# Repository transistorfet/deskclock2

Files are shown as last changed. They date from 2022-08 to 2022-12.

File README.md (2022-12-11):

DeskClock 2
===========

###### *Started July 31, 2022*

A desktop companion device for displaying status and controlling things without interrupting flow.
This is a replacement to my previous deskclock project which was originally built in 2009 and later
revamped with an Arduino in 2012.

The new design has an LCD screen, 8 CherryMX buttons, a temperature sensor, an IR receiver, and a
USB connection to my desktop computer.  The controller is a
[Adafruit Feather STM32F405 Express](https://learn.adafruit.com/adafruit-stm32f405-feather-express)
programmed using the Arudino framework.  The computer is running
[Nerve](http://jabberwocky.ca/projects/nerve/), which can perform actions in response to the
buttons, and display information like the current time, current song playing on my computer, and
indoor and outdoor temperature (where the outdoor temperature is broadcast from another computer,
which receives it from a wireless sensor outside).  The buttons are currently configured to control
the music player on my computer, as well as toggle some lights in my computer room.

Custom PCB
----------

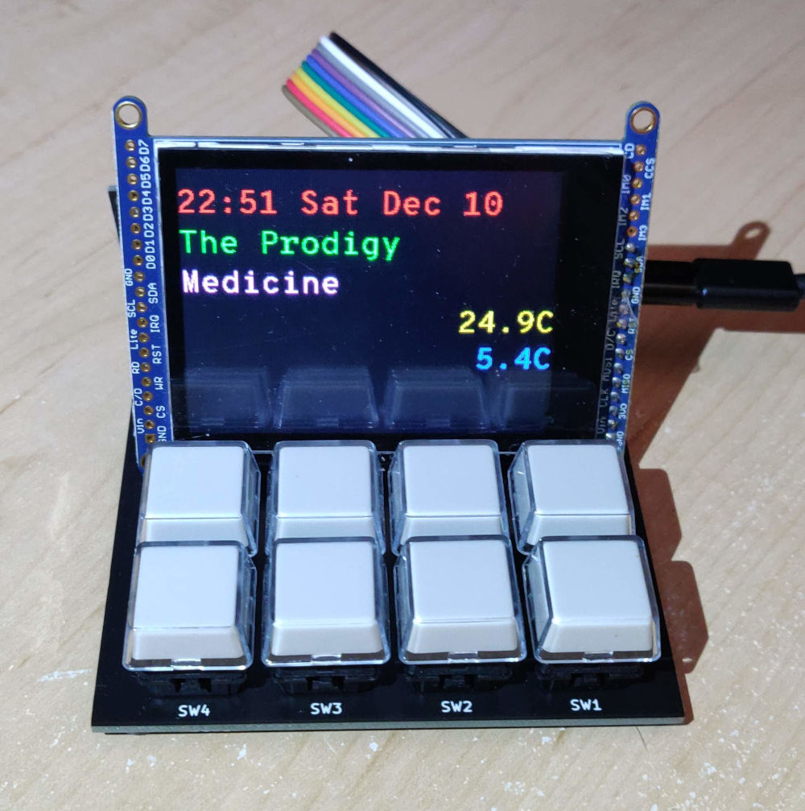
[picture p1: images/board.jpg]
The board in its place under one of my side monitors


Above is the assembled board.  It was designed in November 2022, and assembled in December.

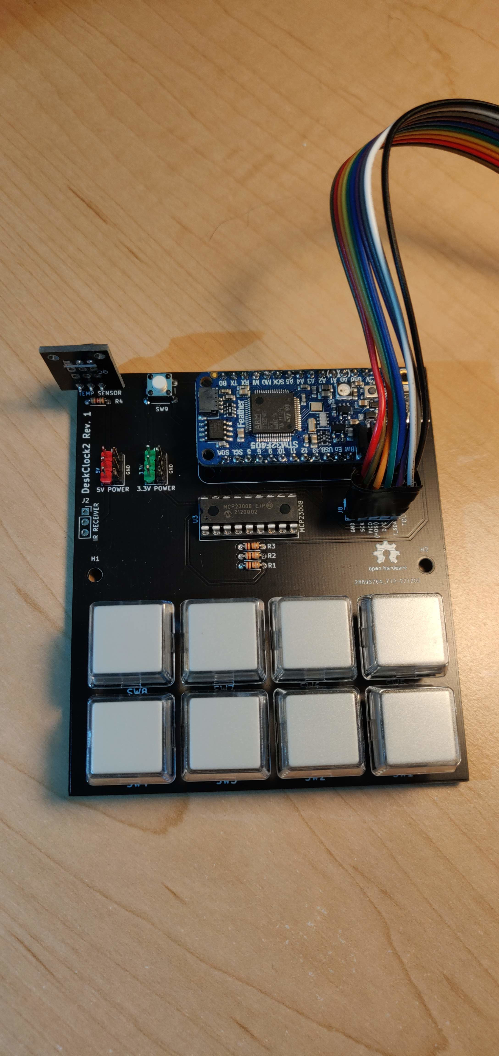
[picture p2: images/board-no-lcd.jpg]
Top view of the assembled board without the LCD showing the components


Top down view of the board without the LCD resting on top.  It's a pretty simple design with
an MCP23008 I2C GPIO chip for reading the buttons.

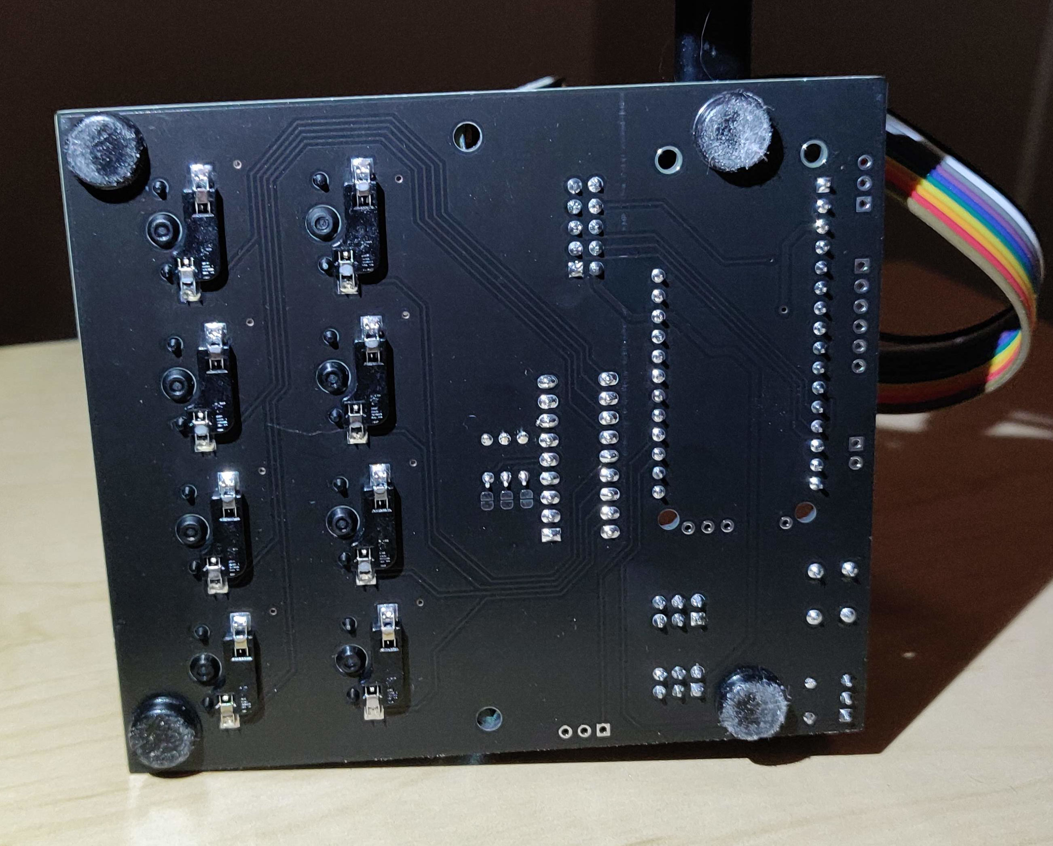
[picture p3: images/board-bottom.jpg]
Bottom view of the assembled board showing the Kali solderless keyboard button sockets


On the bottom, you can see the Kali solderless keyboard button sockets, which are compatible with
CherryMX switches.  They were surprisingly easy to install, align, and solder, using a pre-made
KiCAD footprint.  The sockets snap snugly into the board with no room to wiggle.  I also stuck
some rubber feet to the bottom to clear the sockets from touching the desk, and also to keep it in
place when pressing buttons.

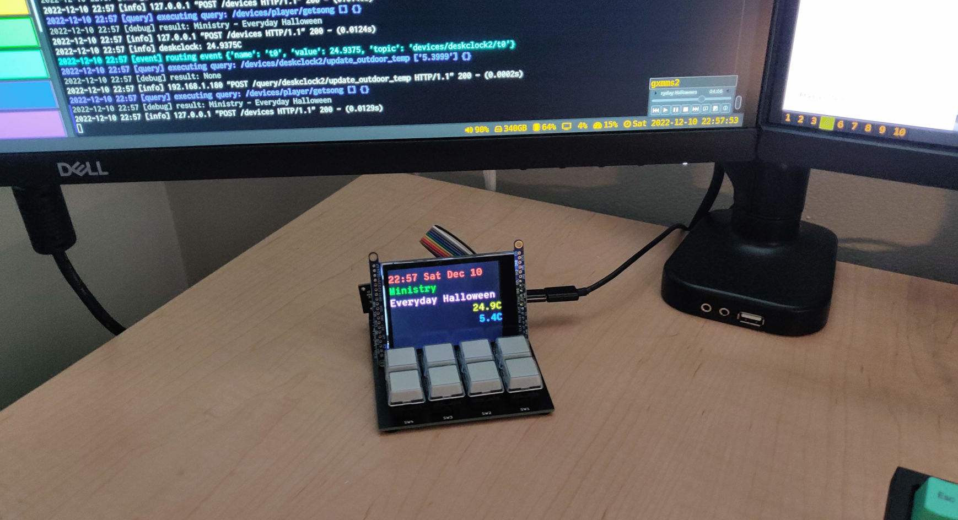
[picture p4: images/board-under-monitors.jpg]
The assembled board, wider view including the monitor with the Python program's log messages showing some communication with the device


The assembled board with the LCD floating (not securely attached). On the monitor above, you can
see the Python program's log messages showing it receiving the outdoor temperature and sending it
to DeskClock2, and querying the current song to be displayed.

A mistake was made on the board for the IR receiver, which has the power pins reversed.  I attached
a 3 pin header to the board, and with some shrink wrap on one of the pins, bent the power pins to
be reversed when plugged in.

Prototype
---------

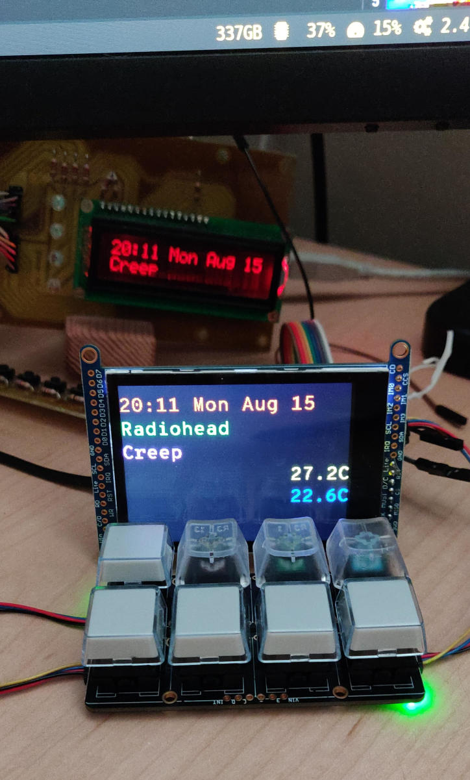
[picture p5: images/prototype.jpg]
Prototype using AdaFruit NeoKeys and 2.8 inch LCD


Above is the prototype, with the old deskclock to be replaced visible in the background

The prototype is built using an Adafruit
[Feather STM32F405 Express](https://learn.adafruit.com/adafruit-stm32f405-feather-express) with two
[NeoKeys](https://www.adafruit.com/product/4980) and a
[2.8 inch LCD](https://www.adafruit.com/product/2090).

Programming with Arduino
------------------------

In the Arduino IDE:

- select board "Generic STM32F4 Series"
- select board part number "Adafruit Feather STM32F405"
- select USB support "CDC (generic 'Serial' supersede USART)
- select upload method "STM32CubeProgrammer (DFU)"

To put the device in programming mode, hold down the reset button on the Feather, and the Flash button
on the board, and then release the reset button first.

Communication
-------------

The Feather appears as a generic serial-over-USB device.  The protocol is a very simple text format
where each line has a sub-device name/number, followed by an equals sign, and then the data.  For a
button, the device would send "B5=1" when the button is pressed, and "B5=0" when released, where the
number in the name corresponds to the button number between 0 and 7.  The temperature is sent back
as "T0=23.0" where the value is in Celsius.

For the LCD, each of 5 lines is drawn with a separate line to allow them to be updated independently
to avoid flicker due to the slow updated time of the LCD over SPI.  Each line has the form
"L2=Some Text" where the number is the line number to updated, between 0 and 4.  The text can
contain a simple escape code for setting the text colour, of the form "\x1B[3m" which would set the
colour to "3" (green).

The LCD is a passive device, displaying whatever the computer tells it to.  The temperature has to
be sent to the computer, and the computer needs to update the LCD with that information to display
it.  On the Nerve/Computer side, the temperature is also data logged along with other sensors around
the house, so that they can all be displayed on a graph through the web interface.

The IR sensor returns data as "I0=N:40:1", where "N" is NEC protocol, "40" is the address number of
the remote control, and "1" in the command code.

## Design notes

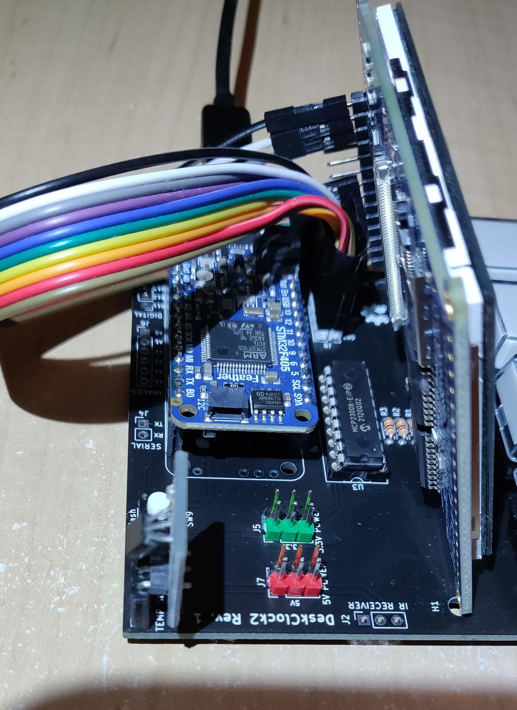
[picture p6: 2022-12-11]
images/board-side.jpg

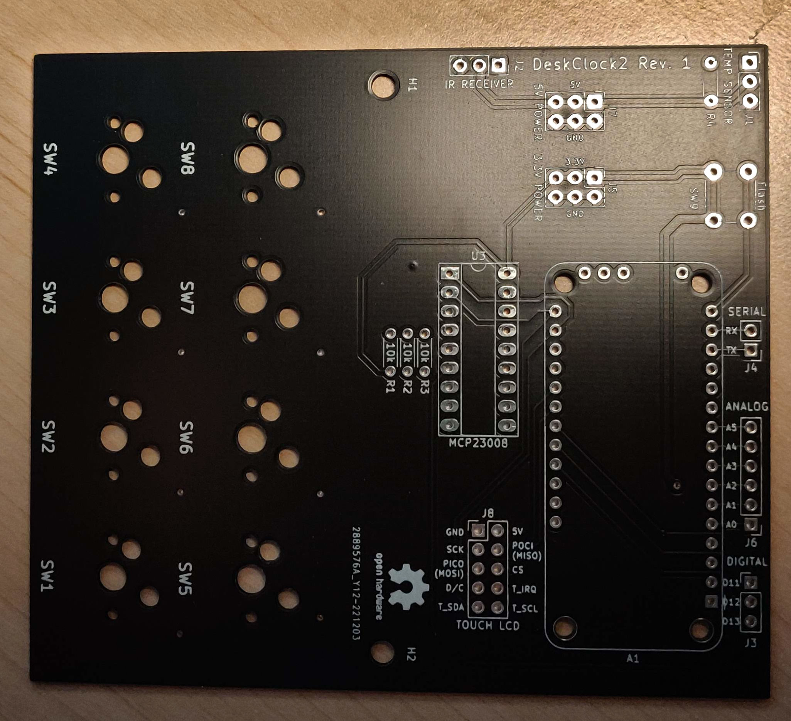
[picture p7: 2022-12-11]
images/board-bare-top.jpg

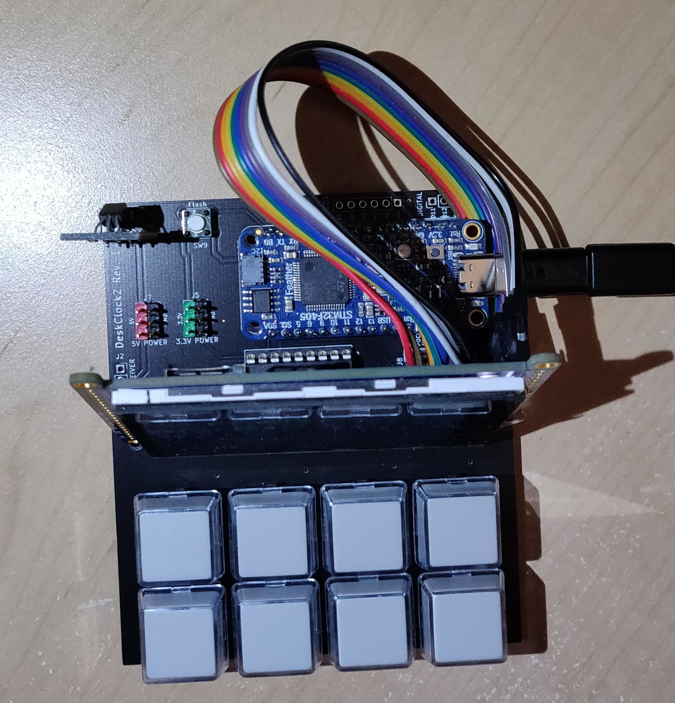
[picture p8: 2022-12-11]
images/board-top.jpg

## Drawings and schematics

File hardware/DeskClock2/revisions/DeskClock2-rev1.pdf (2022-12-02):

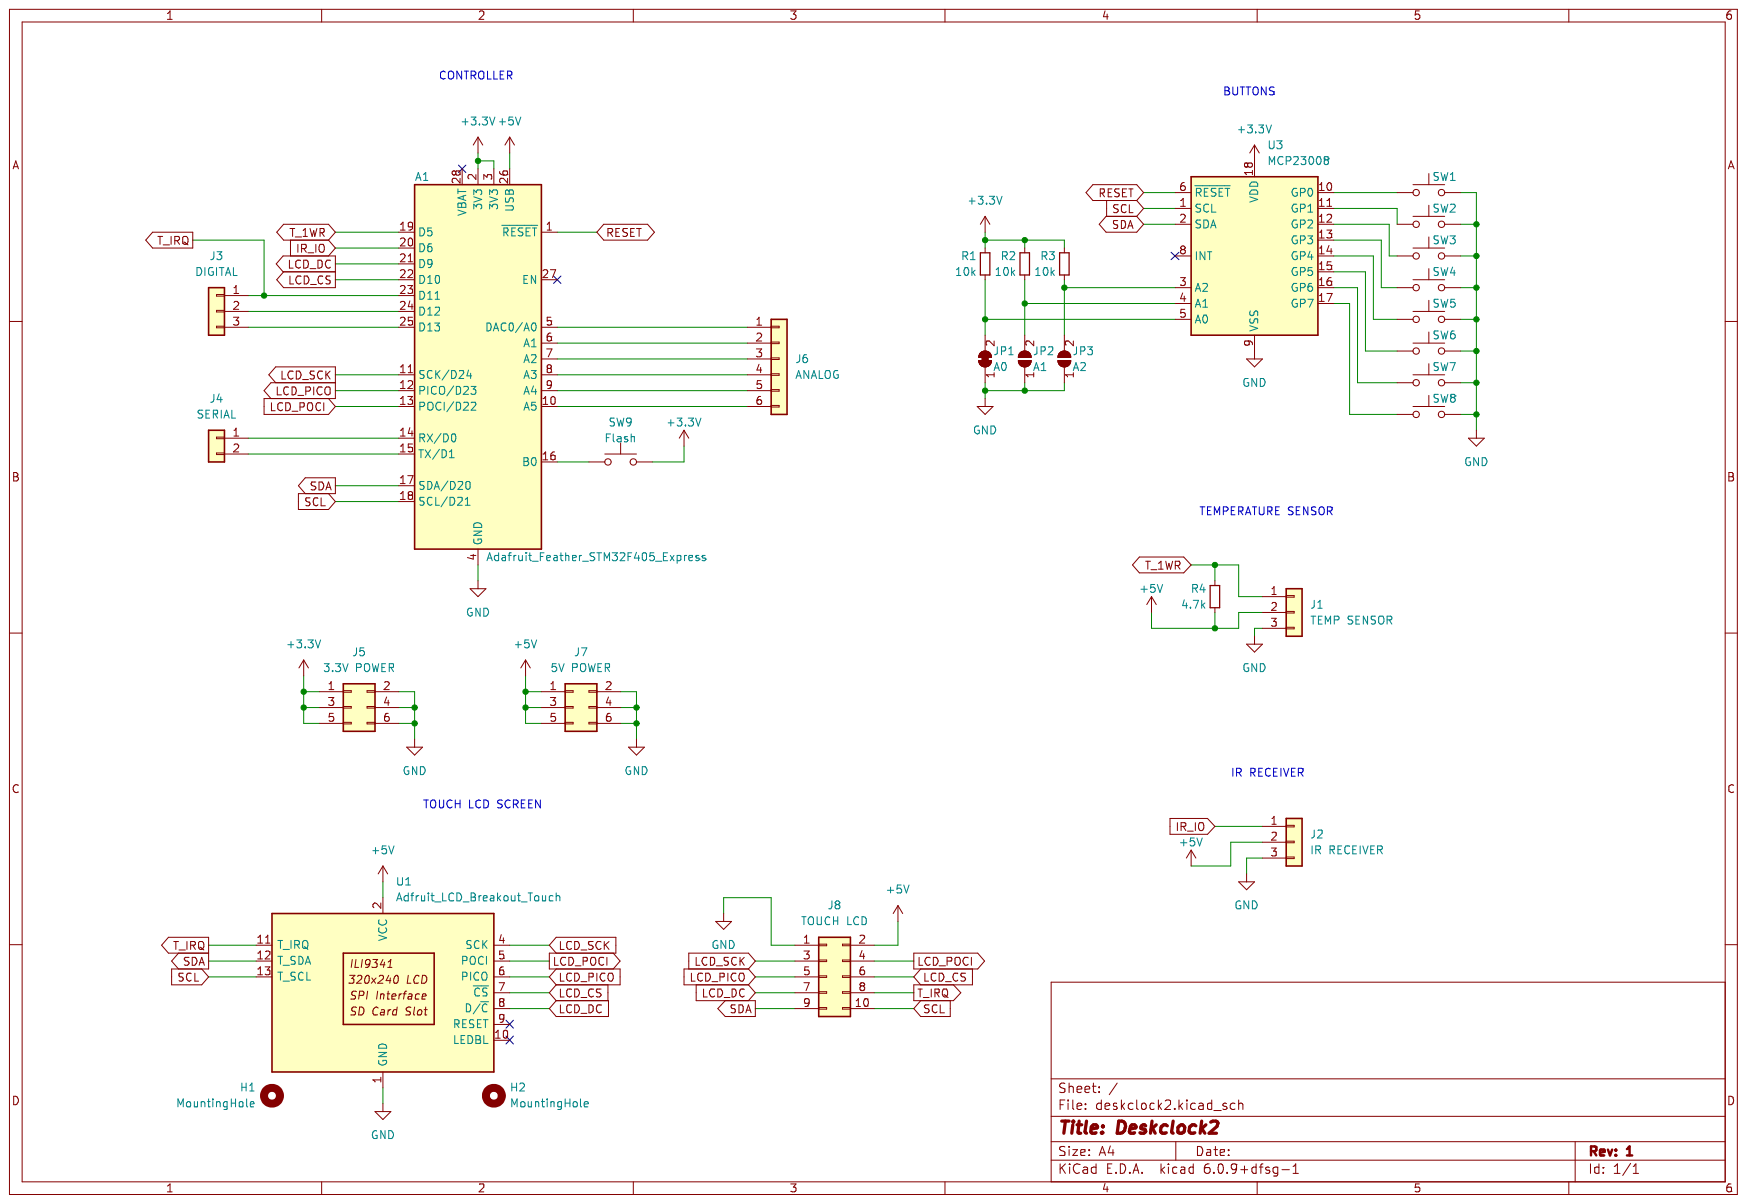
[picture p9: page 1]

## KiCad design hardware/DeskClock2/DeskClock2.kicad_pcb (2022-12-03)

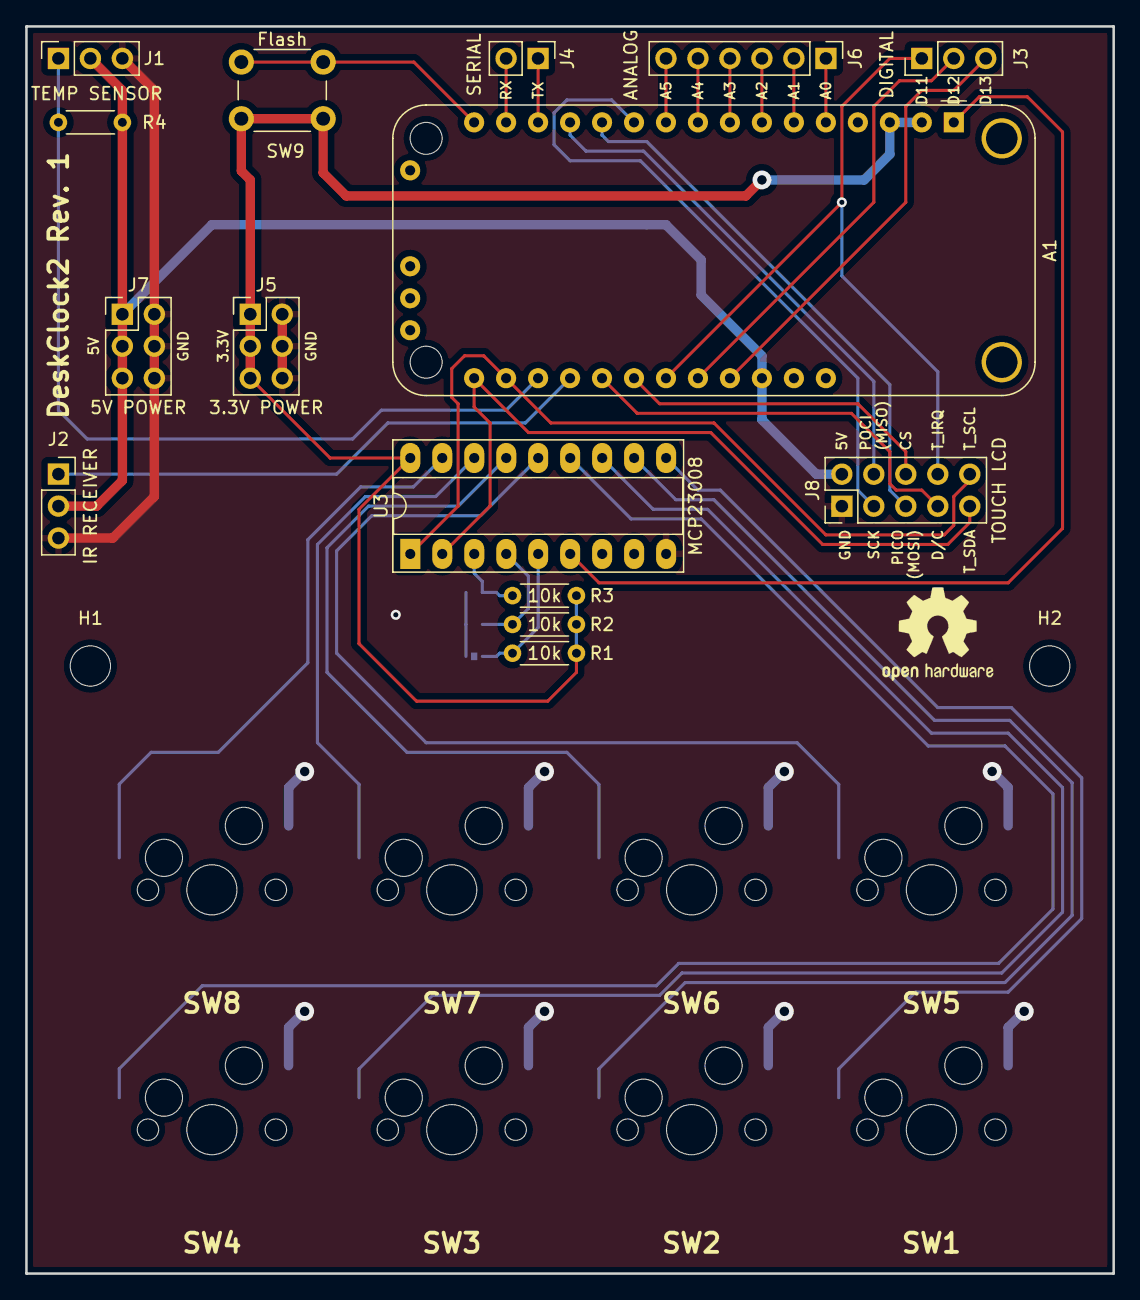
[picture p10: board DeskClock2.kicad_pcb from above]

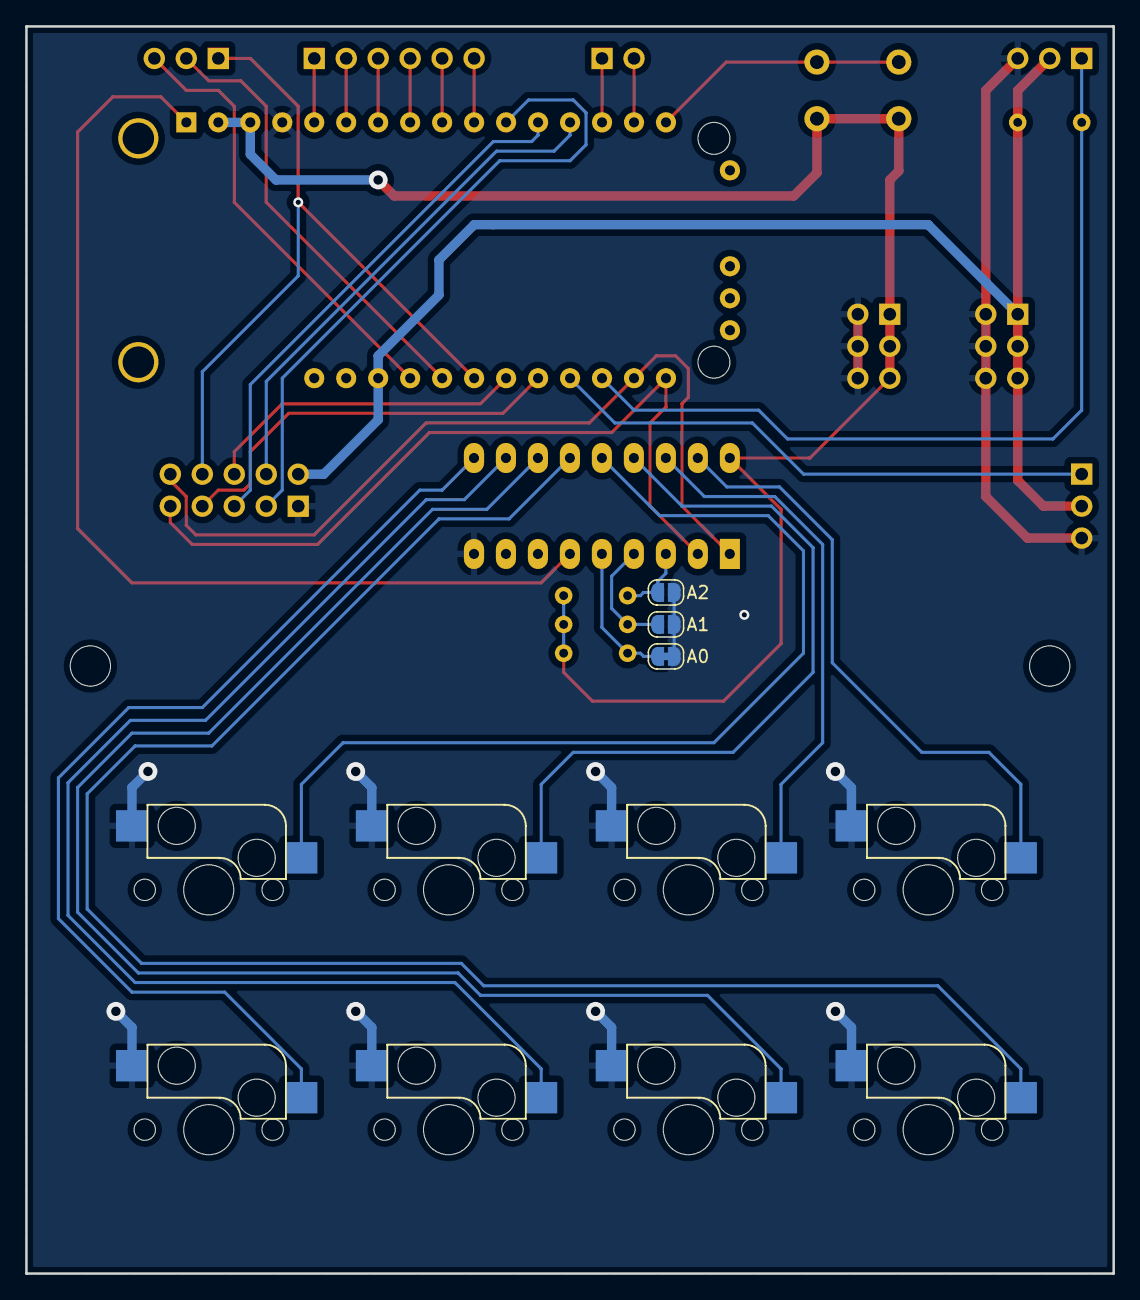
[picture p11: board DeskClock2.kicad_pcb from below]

Board: 2 copper layers, 86.4 x 99.1 mm, 29 parts (11 on the bottom side), 36 nets.

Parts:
A1: Adafruit_Feather_STM32F405_Express; Adafruit_Feather_M0_RFM_WithMountingHoles
H1, H2: MountingHole; MountingHole_3.2mm_M3_DIN965
J1: TEMP SENSOR; PinSocket_1x03_P2.54mm_Vertical
J2: IR RECEIVER; PinSocket_1x03_P2.54mm_Vertical
J3: DIGITAL; PinHeader_1x03_P2.54mm_Vertical
J4: SERIAL; PinHeader_1x02_P2.54mm_Vertical
J5: 3.3V POWER; PinHeader_2x03_P2.54mm_Vertical
J6: ANALOG; PinHeader_1x06_P2.54mm_Vertical
J7: 5V POWER; PinHeader_2x03_P2.54mm_Vertical
J8: TOUCH LCD; PinHeader_2x05_P2.54mm_Vertical
JP1: A0; SolderJumper-2_P1.3mm_Bridged_RoundedPad1.0x1.5mm
JP2: A1; SolderJumper-2_P1.3mm_Open_RoundedPad1.0x1.5mm
JP3: A2; SolderJumper-2_P1.3mm_Open_RoundedPad1.0x1.5mm
R1, R2, R3: 10k; R_Axial_DIN0204_L3.6mm_D1.6mm_P5.08mm_Horizontal
R4: 4.7k; R_Axial_DIN0204_L3.6mm_D1.6mm_P5.08mm_Horizontal
SW1, SW2, SW3, SW4, SW5, SW6, SW7, SW8: SW_Push; Kailh_MX_Socket
SW9: Flash; SW_PUSH_6mm
U1: Adfruit_LCD_Breakout_Touch; OSHW-Logo2_9.8x8mm_SilkScreen
U3: MCP23008; DIP-18_W7.62mm_Socket_LongPads

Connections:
+3.3V: A1.2 (3V3), A1.3 (3V3), J5.1, J5.3, J5.5, R1.1, R2.1, R3.1, SW9.2, U3.18 (VDD)
+5V: A1.26 (USB), J1.2, J2.2, J7.1, J7.3, J7.5, J8.2, R4.2
GND: A1.4 (GND), J1.3, J2.3, J5.2, J5.4, J5.6, J7.2, J7.4, J7.6, J8.1, JP1.1 (A), JP2.1 (A), JP3.1 (A), SW1.2, SW2.2, SW3.2, SW4.2, SW5.2, SW6.2, SW7.2, SW8.2, U3.9 (VSS)
IR_IO: A1.20 (D6), J2.1
LCD_CS: A1.22 (D10), J8.6
LCD_DC: A1.21 (D9), J8.7
LCD_PICO: A1.12 (PICO/D23), J8.5
LCD_POCI: A1.13 (POCI/D22), J8.4
LCD_SCK: A1.11 (SCK/D24), J8.3
unnamed: A1.5 (DAC0/A0), J6.1
unnamed: A1.6 (A1), J6.2
unnamed: A1.7 (A2), J6.3
unnamed: A1.8 (A3), J6.4
unnamed: A1.9 (A4), J6.5
unnamed: A1.10 (A5), J6.6
unnamed: A1.14 (RX/D0), J4.1
unnamed: A1.15 (TX/D1), J4.2
unnamed: A1.16 (B0), SW9.1
unnamed: A1.24 (D12), J3.2
unnamed: A1.25 (D13), J3.3
unnamed: JP1.2 (B), R1.2, U3.5 (A0)
unnamed: JP2.2 (B), R2.2, U3.4 (A1)
unnamed: JP3.2 (B), R3.2, U3.3 (A2)
unnamed: SW1.1, U3.10 (GP0)
unnamed: SW2.1, U3.11 (GP1)
unnamed: SW3.1, U3.12 (GP2)
unnamed: SW4.1, U3.13 (GP3)
unnamed: SW5.1, U3.14 (GP4)
unnamed: SW6.1, U3.15 (GP5)
unnamed: SW7.1, U3.16 (GP6)
unnamed: SW8.1, U3.17 (GP7)
RESET: A1.1 (~RESET), U3.6 (~RESET)
SCL: A1.18 (SCL/D21), J8.10, U3.1 (SCL)
SDA: A1.17 (SDA/D20), J8.9, U3.2 (SDA)
T_1WR: A1.19 (D5), J1.1, R4.1
T_IRQ: A1.23 (D11), J3.1, J8.8

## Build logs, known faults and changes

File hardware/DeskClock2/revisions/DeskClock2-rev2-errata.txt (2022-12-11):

 
Revision 1 Errata and Notes
===========================

- the IR receiver pinout has the power pins backwards, which causes the sensor to heat up and die

- the silkscreen button labels are the opposite order to what the button numbers are in firmware,
  where the computer side matches the firmware.  The "Next" button is B7 in software, but SW1 on
  the silkscreen.  I'm pretty sure the software ordering has carried on since the original
  deskclock

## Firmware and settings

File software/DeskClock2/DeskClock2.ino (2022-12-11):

/**
 * DeskClock2 - A Desktop Companion Device
 */

#include <DallasTemperature.h>
#include <OneWire.h>

#include <IRremote.h>

#include <SPI.h>
#include <Adafruit_GFX.h>
#include <Adafruit_ILI9341.h>

#include <Wire.h>


#define FONT    OverpassMono14pt7b
#include "OverpassMono14pt7b.h"
#define TEXT_LINE_HEIGHT    20
#define TEXT_MAX_HEIGHT     24

//#define FONT    Inconsolata18pt7b
//#include "Fonts/Inconsolata18pt7b.h"


#define SCREEN_WIDTH    320
#define SCREEN_HEIGHT   240

// For the Adafruit shield, these are the default.
#define TFT_DC      9
#define TFT_CS      10
//#define TFT_RST     5
//#define TFT_CLK     6
//#define TFT_MOSI    11
//#define TFT_MISO    12

Adafruit_ILI9341 tft = Adafruit_ILI9341(TFT_CS, TFT_DC);

const GFXfont *font = &FONT;


#define RGB(r, g, b)    ((r) << 11) | ((g) << 5) | (b)

//define some colour values
#define BLACK           0x0000
#define BLUE            0x001F
#define RED             0xF800
#define GREEN           0x07E0
#define CYAN            0x07FF
#define MAGENTA         0xF81F
#define YELLOW          0xFFE0
#define WHITE           0xFFFF
#define DARKGREEN       RGB(0, 48, 0)
#define DARKYELLOW      RGB(31, 56, 0)


word colours[] = {
    BLACK,
    BLUE,
    RED,
    GREEN,
    CYAN,
    MAGENTA,
    YELLOW,
    WHITE,
    DARKGREEN,
    DARKYELLOW,
};


/******************************
 * Serial Communications Code *
 ******************************/

#define SERIAL_SIZE     512

char serial_r = 0;
char serial_avail = 0;
char serial_rb[SERIAL_SIZE];

void read_serial()
{
    int b;

    if (serial_avail == 1)
        return;

    b = Serial.read();
    if (b == -1)
        return;

    serial_rb[serial_r] = b;
    if (b == '\n')
        serial_avail = 1;
    if (serial_r < SERIAL_SIZE)
        serial_r++;
}

void clear_serial()
{
    serial_avail = 0;
    serial_r = 0;
}


void process_msg()
{
    int val;

    if (!serial_avail)
        return;
    serial_rb[serial_r] = '\0';

    if (serial_rb[0] == 'L') {
        if (serial_rb[2] == '=') {
            byte lineno = serial_rb[1] - '0';
            tft.setCursor(0, (1 + lineno) * font->yAdvance);
            tft.fillRect(0, tft.getCursorY() - TEXT_LINE_HEIGHT, SCREEN_WIDTH, TEXT_LINE_HEIGHT + 7, BLACK);

            char *start = &serial_rb[3];
            for (int i = 3; serial_rb[i] != '\0'; i++) {
                if (serial_rb[i] == '\r' || serial_rb[i] == '\n') {
                    serial_rb[i] = '\0';
                    tft.println(start);
                    start = &serial_rb[i + 1];
                } else if (serial_rb[i] == '\x1b' && serial_rb[i + 1] == '[') {
                    serial_rb[i] = '\0';
                    tft.print(start);
                    start = &serial_rb[i + 4];

                    byte type;
                    i += 2;

                    val = serial_rb[i] - '0';
                    type = serial_rb[++i];
                    tft.setTextColor(colours[val]);
                }
            }
        }
    }
    clear_serial();
}


/************************
 * Button Debounce Code *
 ************************/

#define I2C_GPIO_ADDR    0x26

#define NUM_BUTTONS    8
unsigned long button_last = 0;
unsigned int button_st[NUM_BUTTONS];
char button_ch[NUM_BUTTONS];
char buttons[NUM_BUTTONS];

void init_buttons()
{
    Wire.begin();

    Wire.beginTransmission(I2C_GPIO_ADDR);

    // Set GPPU (Pull-Ups) to On
    Wire.write(0x06);
    Wire.write(0xff);

    Wire.endTransmission();

    for (int i = 0; i < NUM_BUTTONS; i++) {
        buttons[i] = 0;
        button_ch[i] = 0;
        button_st[i] = 0;
    }
}

void debounce_buttons()
{
    uint8_t button_values;

    button_values = read_buttons();

    if ((millis() - button_last) < 3)
        return;

    button_last = millis();
    for (int i = 0; i < NUM_BUTTONS; i++) {
        button_st[i] <<= 1;
        button_st[i] |= (button_values >> (NUM_BUTTONS - i - 1)) & 0x01;
        if (buttons[i] == 0) {
            /// If at least one bit is not zero, then call it a 1
            if (button_st[i] != 0) {
                buttons[i] = 1;
                button_ch[i] = 1;
            }
        }
        else {
            /// If it's all zeros then call it a 0
            if (button_st[i] == 0) {
                buttons[i] = 0;
                button_ch[i] = 1;
            }
        }
    }
}

void process_buttons()
{
    for (int i = 0; i < NUM_BUTTONS; i++) {
        if (button_ch[i]) {
            Serial.print('B');
            Serial.print(i);
            Serial.print('=');
            Serial.print(buttons[i], HEX);
            Serial.print('\n');
            button_ch[i] = 0;
        }
    }
}

byte read_buttons()
{
    char buttons;

    // Request read GPIO (Input values)
    Wire.beginTransmission(I2C_GPIO_ADDR);
    Wire.write(0x09);
    Wire.endTransmission();

    // Wait to read data
    Wire.requestFrom(I2C_GPIO_ADDR, 1);

    while (Wire.available()) {
        buttons = Wire.read();
    }

    return ~buttons;
}


/**********************
 * Temperature Sensor *
 **********************/

#define PIN_TEMP    5

OneWire oneWire(PIN_TEMP);
DallasTemperature sensors(&oneWire);

void init_temperature()
{
	sensors.begin();
}

void send_temperature()
{
	sensors.requestTemperatures();
	Serial.print("T0=");
	Serial.print(sensors.getTempCByIndex(0), 4);
	Serial.print('\n');
}


/********************
 * IR Recevier Code *
 ********************/

#define PIN_IRRX      6

IRData ir_last;

void init_ir(void)
{
    IrReceiver.begin(PIN_IRRX, DISABLE_LED_FEEDBACK);
}

int read_ir(void)
{
    if (!IrReceiver.decode())
        return 0;

    ir_last = IrReceiver.decodedIRData;
    IrReceiver.resume();

    if (!(IrReceiver.decodedIRData.flags & IRDATA_FLAGS_IS_REPEAT))
        return 1;
    else
        return 0;
}

void process_ir(void)
{
    if (read_ir()) {
        Serial.print("I0=");
        Serial.print(get_protocol(ir_last.protocol));
        Serial.print(':');
        Serial.print(ir_last.address, HEX);
        Serial.print(':');
        Serial.print(ir_last.command, HEX);
        Serial.print('\n');
    }
}

char *get_protocol(decode_type_t protocol)
{
    switch (protocol) {
        case NEC:
            return "N";
        case PANASONIC:
            return "P";
        case SONY:
            return "S";
        case ONKYO:
            return "O";
        case JVC:
            return "J";
        case SHARP:
            return "SH";
        case DENON:
            return "D";
        case LG:
        case LG2:
            return "L";
        case RC5:
            return "RC5";
        case RC6:
            return "RC6";
        case SAMSUNG:
            return "SA";
        case APPLE:
            return "A";
        default:
            return "x";
    }
}


/*********************
 * Setup & Main Loop *
 *********************/

void setup()
{
    Serial.begin(115200);
    clear_serial();

    tft.begin();
    tft.setRotation(1);
    tft.setFont(font);
    tft.setTextSize(1);
    tft.fillScreen(ILI9341_BLACK);

    init_buttons();

    init_ir();
    init_temperature();
}

unsigned long last_time = 0;

void loop()
{
    char ret = 0;
    
    debounce_buttons();
    read_serial();

    process_buttons();
    process_msg();

    process_ir();

    if (millis() - last_time > 30000) {
        last_time = millis();
        send_temperature();
    }
}

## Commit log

2022-08-18 Added temperature sensor
2022-11-14 Added first draft of hardware and PCB design
    [deskclock2.kicad_pcb, deskclock2.kicad_sch]
2022-12-02 Revision 1 complete
    [deskclock2.kicad_pcb, deskclock2.kicad_sch]
2022-12-03 Changed capitalization of file names in hardware/
    [DeskClock2.kicad_pcb, DeskClock2.kicad_sch]
2022-12-11 Completed assembly of the board
